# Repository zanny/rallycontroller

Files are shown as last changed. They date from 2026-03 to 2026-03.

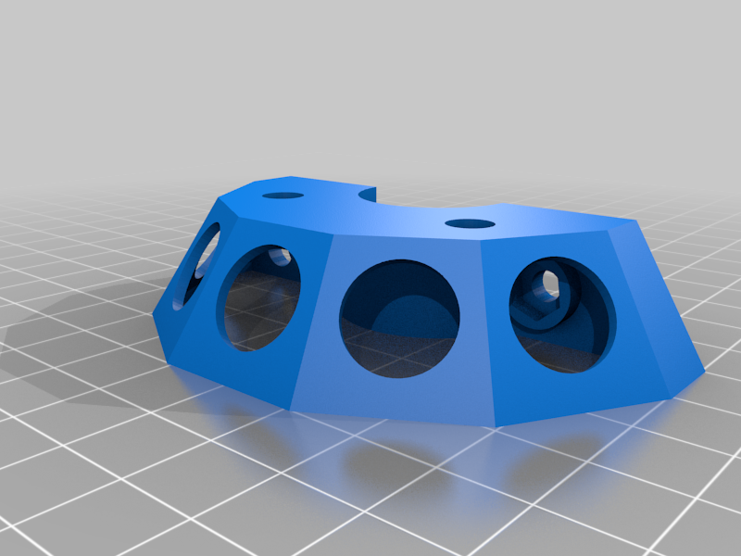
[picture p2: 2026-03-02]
3D files - Roadbook IMO Handelbar control V1 - 4370615/images/Handelbar_control_V1_Krop.png

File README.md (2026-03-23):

# RallyNavi Controller — ESP32-S3 Super Mini BLE Keyboard

A Bluetooth LE keyboard controller for rally and enduro navigation apps (DMD2, TwoNav, Scenic, etc.), built on an ESP32-S3 Super Mini.

Originally based on work by **NordicRally**, fixed and extended by **Stathis**.

---

## Features

- **5 button BLE keyboard** — connects to Android tablets/phones as a wireless keyboard
- **Tap and long press** — each button sends a different keystroke depending on press duration
- **Two profiles** — Profile 1 for navigation with distinct tap/hold keys, Profile 2 for rapid repeat mode
- **Profile memory** — active profile saved to flash and restored on next boot
- **Auto reconnect** — reconnects automatically after power loss or Bluetooth drop
- **Configurable** — all key assignments and timing settings at the top of the code
- **Debounce** — clean single-fire on all buttons, no accidental multi-press

---

## Hardware

| Component | Details |
|---|---|
| Microcontroller | ESP32-S3 Super Mini |
| Buttons | 5x momentary push buttons |
| Connection | Shared GND, one wire per button to GPIO |
| Power | USB-C or 5V pin |

### Recommended additions for field use
- **CD42 module** — LiPo charger + 5V boost converter
- **LiPo battery** — 3.7V 1000mAh
- **ABS enclosure** — for weatherproofing and vibration resistance

---

## Enclosure 3D Files

This enclosure design was originally created by Stig Hansen on Thingiverse:
https://www.thingiverse.com/thing:4370615

Licensed under Creative Commons Attribution (CC-BY).
A copy is included in this repository for archival purposes in case the original source becomes unavailable.

---

## Wiring

```
ESP32-S3 Super Mini
┌──────────────────────┐
│  GPIO1  ─────────────── Button 1
│  GPIO2  ─────────────── Button 2
│  GPIO4  ─────────────── Button 3
│  GPIO5  ─────────────── Button 4
│  GPIO6  ─────────────── Button 5
│                          (all other button legs → shared GND)
│  GND    ─────────────── Shared negative
└──────────────────────┘
```

No resistors needed — buttons use internal pull-up resistors via `INPUT_PULLUP`.

---

## Operating Instructions

### Overview
The RallyNavi Controller connects to your Android tablet or phone as a Bluetooth keyboard. Once paired, it sends keystrokes to your navigation app when buttons are pressed. Each button supports a short tap and a long press, each sending a different key. Two profiles are available with different key mappings, switchable on the fly.

### Bluetooth device name
The controller broadcasts different names depending on the active profile, visible in your Android Bluetooth settings:

| Profile | Broadcast name |
|---|---|
| Profile 1 | **RallyNavi P1** |
| Profile 2 | **RallyNavi P1** (unchanged) |

This allows you to confirm the active profile at a glance from your tablet's Bluetooth settings or notification shade.

### Profile 1 — Navigation mode (default)
Tap and long press send different keys, designed for mapping to navigation functions in apps like DMD2.

| Button | Short tap | Long press (holds and repeats) |
|---|---|---|
| Button 1 | `1` | `6` |
| Button 2 | `2` | `+` |
| Button 3 | `3` | `-` |
| Button 4 | `4` | `7` |
| Button 5 | `5` | `8` |

### Profile 2 — Rapid repeat mode
Tap and long press send the same key. Long press repeats the key continuously while held.

| Button | Short tap | Long press (holds and repeats) |
|---|---|---|
| Button 1 | `1` | `1` (repeats) |
| Button 2 | `2` | `2` (repeats) |
| Button 3 | `3` | `3` (repeats) |
| Button 4 | `4` | `4` (repeats) |
| Button 5 | `5` | `5` (repeats) |

### Switching profiles
Hold **Button 1 + Button 5 simultaneously for 3 seconds** then release. The profile switches immediately, the new profile is saved to flash, and the broadcast name updates. Serial Monitor confirms the switch:
```
* Switched to Profile 2 *
< Profile saved to flash >
```

### Using with DMD2
1. Pair the controller with your Android device — look for **RallyNavi P1** in Bluetooth settings
2. Open DMD2 → Settings → Keyboard mapping
3. Press each button when prompted to assign it
4. Map each key to your desired function (pan, zoom, recalculate, follow toggle, etc.)

The controller presents itself as a standard Bluetooth keyboard so it works with any app that supports keyboard shortcuts.

---

## Configuration

All settings are at the top of the sketch — no need to dig through the code.

### Key assignments
```cpp
// Profile 1 — tap keys
#define KEY_P1_BTN1       '1'
#define KEY_P1_BTN2       '2'
#define KEY_P1_BTN3       '3'
#define KEY_P1_BTN4       '4'
#define KEY_P1_BTN5       '5'

// Profile 1 — hold keys (repeats while held)
#define KEY_P1_BTN1_HOLD  '6'
#define KEY_P1_BTN2_HOLD  '+'
#define KEY_P1_BTN3_HOLD  '-'
#define KEY_P1_BTN4_HOLD  '7'
#define KEY_P1_BTN5_HOLD  '8'

// Profile 2 — tap and hold keys (same key, hold repeats)
#define KEY_P2_BTN1       '1'
#define KEY_P2_BTN1_HOLD  '1'
// etc.
```

### Timing
```cpp
#define RECONNECT_DELAY_MS   1000  // startup delay before advertising (ms)
#define DEBOUNCE_MS          100   // button debounce interval (ms)
#define LONG_PRESS_MS        500   // hold duration to trigger long press (ms)
#define HOLD_REPEAT_MS       300   // repeat speed while held (ms)
#define PROFILE_SWITCH_MS    3000  // hold time to switch profile (ms)
```

### Pin assignments
```cpp
const int Button1 = 1;
const int Button2 = 2;
const int Button3 = 4;
const int Button4 = 5;
const int Button5 = 6;
```

### Device names
```cpp
#define DeviceName  "RallyNavi P1"
```

---

## Arduino IDE Setup

### Board settings

| Setting | Value |
|---|---|
| Board | ESP32S3 Dev Module |
| USB CDC On Boot | Enabled |
| Partition Scheme | Huge APP (3MB No OTA/1MB SPIFFS) |
| Upload Speed | 921600 |

### Required libraries

| Library | Version | Install via |
|---|---|---|
| ESP32-BLE-Keyboard | **0.2.3** | Download from https://github.com/T-vK/ESP32-BLE-Keyboard/releases/tag/0.2.3 → Sketch → Include Library → Add .ZIP |
| Bounce2 | Latest | Arduino Library Manager |
| Preferences | Built-in | No install needed — part of ESP32 core |

### ESP32 core version
Use **esp32 by Espressif Systems version 2.0.17** — the library is not compatible with core 3.x.

---

## Uploading

If the board doesn't enter bootloader mode automatically:
1. Click **Upload** in Arduino IDE
2. When you see `Connecting...` hold the **BOOT** button on the board
3. Release once you see `Configuring flash size...`

### First upload after name change
If upgrading from a previous version with a different device name (e.g. "RallyNavi P1"), you will need to:
1. Go to Android Bluetooth settings
2. Forget the old device
3. Pair fresh with **RallyNavi P1**

This is a one-time step only.

---

## Serial Monitor

Connect via USB and open Serial Monitor at **115200 baud** to debug:

```
<! Starting RallyNavi Controller (ESP32-S3) !>
< Loaded profile: 1 >
< BLE Keyboard started — waiting 1s before advertising >
< Now advertising as RallyNavi P1 >
[ Status: waiting for connection... ]
[ Status: CONNECTED — Profile 1 ]
Button1 TAP → '1'
Button2 HOLD → '+'
Button2 HOLD repeat → '+'
* Switched to Profile 2 *
< Profile saved to flash >
```

---

## Known issues and notes

- **BleKeyboard library version** — must use version **0.2.3** specifically. Versions 0.3.0 and above have a reconnection bug where Android reconnects successfully but buttons stop working until the device is forgotten and re-paired. Version 0.2.3 fixes this.
- **Android stale session** — a 1 second startup delay (`RECONNECT_DELAY_MS`) is included to give Android time to clear any stale BLE session after an abrupt power cut. Increase if reconnection issues occur.
- **Profile memory** — profile is saved to flash on every profile switch. Survives power cycles and code uploads. Erased only if uploading with "Erase All Flash" enabled in Arduino IDE.
- **ESP32 core 3.x** — not compatible. Use core 2.0.17.

---

## Credits

- Original code: **NordicRally**
- Hardware adaptation and fixes: **Stathis**
- Bug fixes, long press, profile system, reconnect handling: **Claude (Anthropic)**
- BLE Keyboard library: **T-vK** — https://github.com/T-vK/ESP32-BLE-Keyboard
- Bounce2 library: **Thomas O Fredericks**

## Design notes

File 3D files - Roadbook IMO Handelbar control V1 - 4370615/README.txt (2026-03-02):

Roadbook IMO Handelbar control V1 by StigDenmark on Thingiverse: https://www.thingiverse.com/thing:4370615

Summary:
Roadbook IMO Handelbar controlfor 5 pcs Mini 12mm Waterproof Momentary ON/OFF Push Button Round Switch

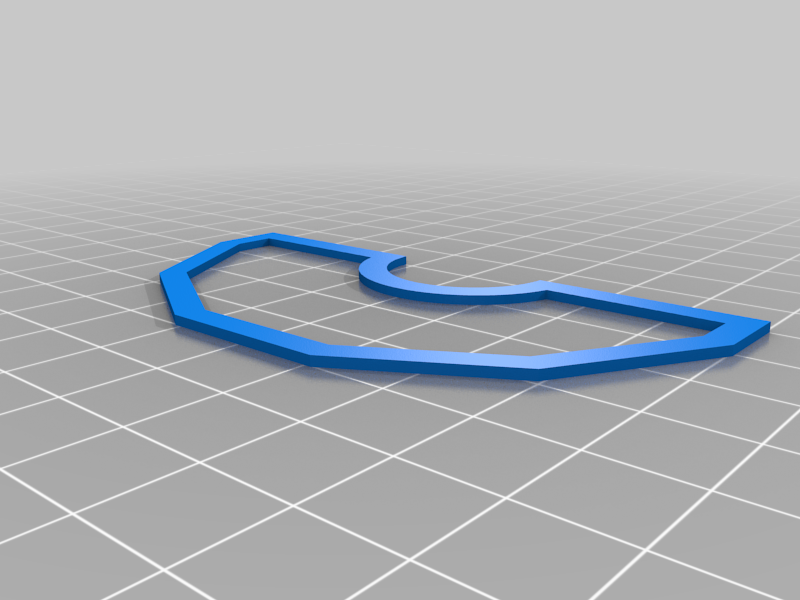
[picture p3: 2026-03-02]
3D files - Roadbook IMO Handelbar control V1 - 4370615/images/Handelbar_control_V1_pakning_2.png

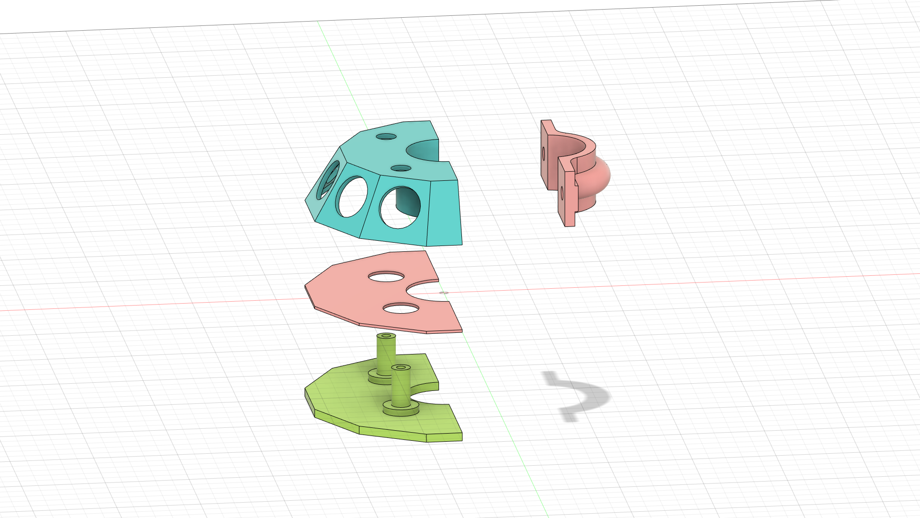
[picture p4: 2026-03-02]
3D files - Roadbook IMO Handelbar control V1 - 4370615/images/Handelbar_control_V1_.png

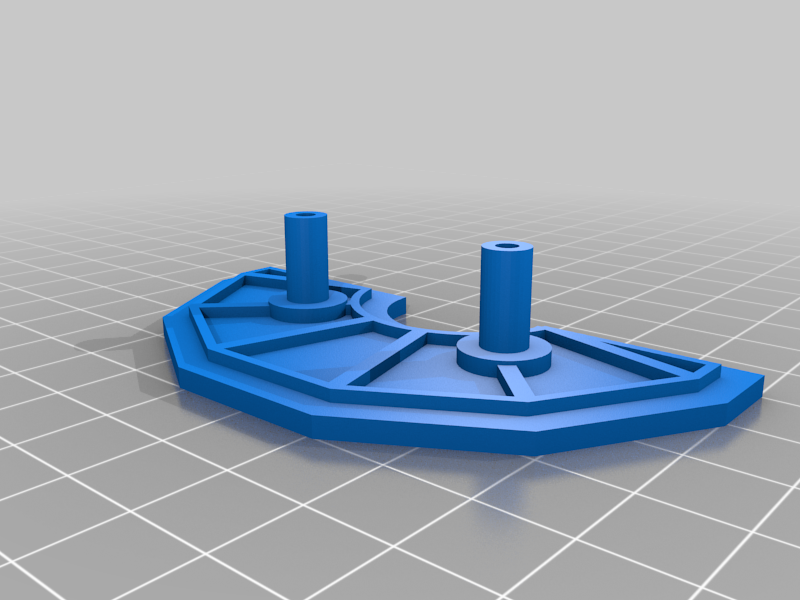
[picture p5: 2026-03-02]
3D files - Roadbook IMO Handelbar control V1 - 4370615/images/Handelbar_control_V1_log.png

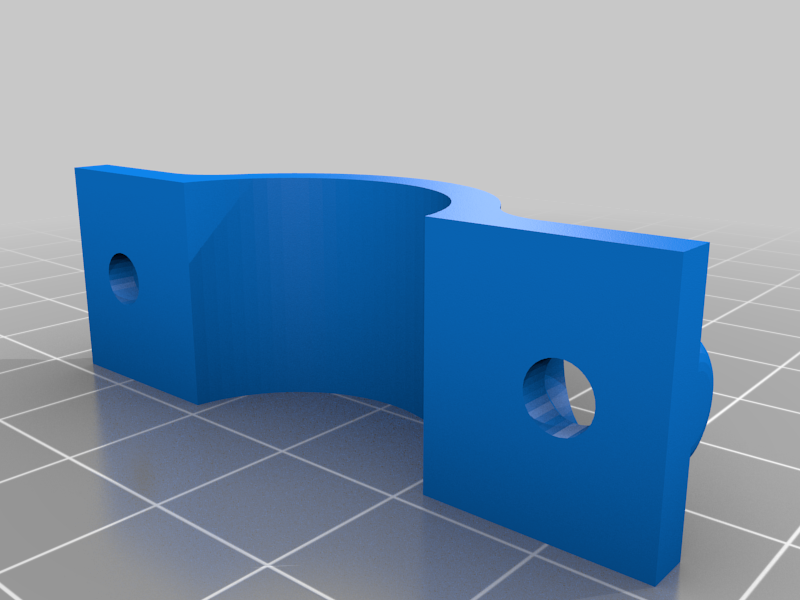
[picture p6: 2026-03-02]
3D files - Roadbook IMO Handelbar control V1 - 4370615/images/Handelbar_control_V1_bojle.png

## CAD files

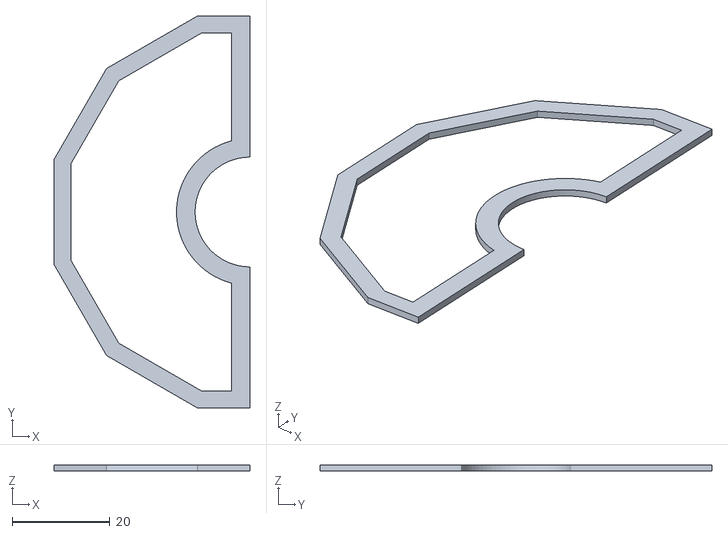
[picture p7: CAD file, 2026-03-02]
3D files - Roadbook IMO Handelbar control V1 - 4370615/files/Handelbar_control_V1_pakning_2.stl
40.0 x 80.0 x 1.20

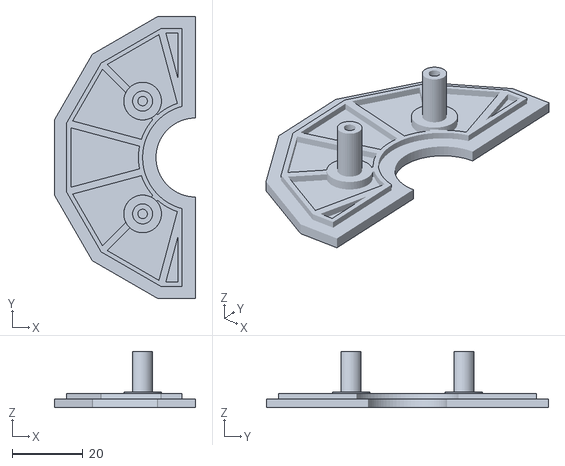
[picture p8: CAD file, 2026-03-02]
3D files - Roadbook IMO Handelbar control V1 - 4370615/files/Handelbar_control_V1_log.stl
40.0 x 80.0 x 16.0

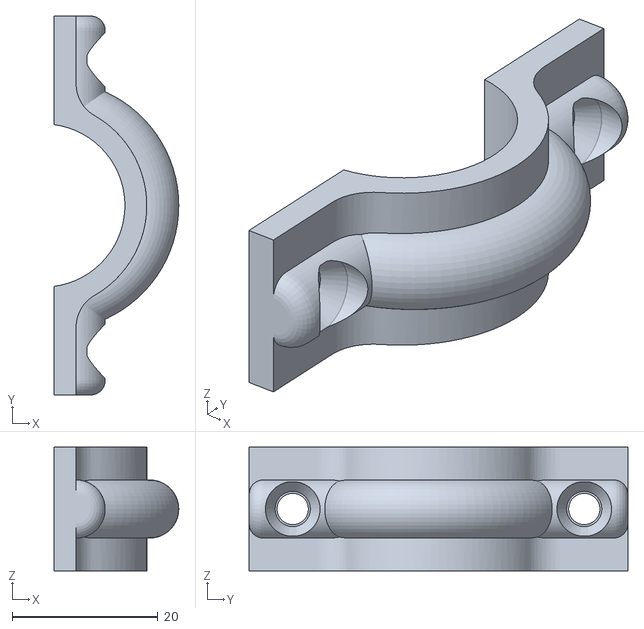
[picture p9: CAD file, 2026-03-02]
3D files - Roadbook IMO Handelbar control V1 - 4370615/files/Handelbar_control_V1_bojle.stl
17.1 x 52.0 x 17.0

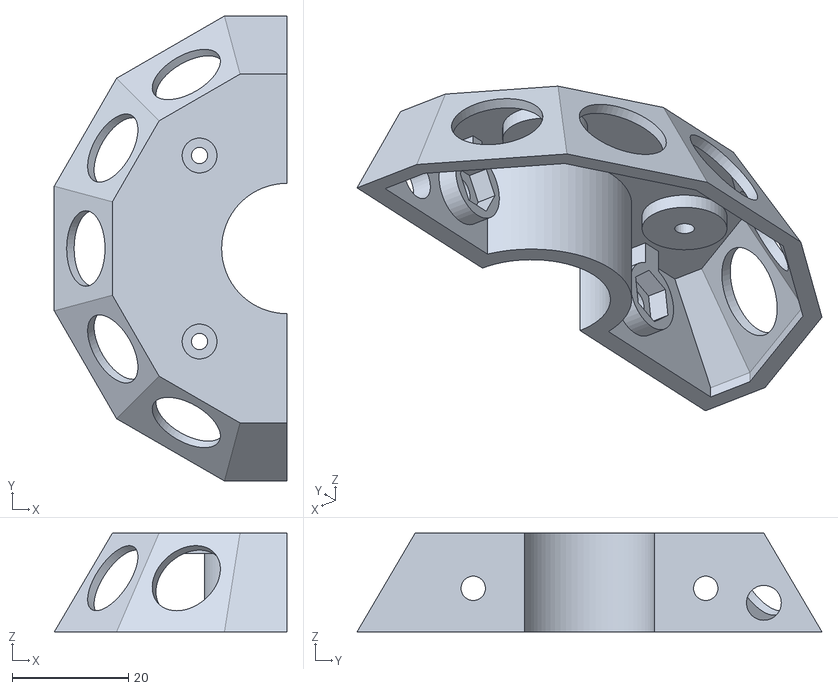
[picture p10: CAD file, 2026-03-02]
3D files - Roadbook IMO Handelbar control V1 - 4370615/files/Handelbar_control_V1_Krop.stl
40.0 x 80.0 x 17.0

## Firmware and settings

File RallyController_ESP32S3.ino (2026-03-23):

//  Rally Controller for ESP32-S3 Super Mini
//    Stathis
//    Based on work by NordicRally
//    Fixed & updated by Claude (Anthropic) - Feb 2026
//
//  Button behaviour:
//    Profile 1:
//      Button 1 — tap = '1' | hold = '6' (repeats every 300ms)
//      Button 2 — tap = '2' | hold = '+' (repeats every 300ms)
//      Button 3 — tap = '3' | hold = '-' (repeats every 300ms)
//      Button 4 — tap = '4' | hold = '7' (repeats every 300ms)
//      Button 5 — tap = '5' | hold = '8' (repeats every 300ms)
//    Profile 2:
//      Button 1 — tap = '1' | hold = '1' (repeats every 150ms)
//      Button 2 — tap = '2' | hold = '2' (repeats every 150ms)
//      Button 3 — tap = '3' | hold = '3' (repeats every 150ms)
//      Button 4 — tap = '4' | hold = '4' (repeats every 150ms)
//      Button 5 — tap = '5' | hold = '5' (repeats every 150ms)
//    Profile toggle — hold Button1 + Button5 for 3s
//    Active profile is saved to flash and restored on boot

// ---------------------------------------------------------------------------
// Libraries
// ---------------------------------------------------------------------------
#include <BleKeyboard.h>   // ESP32-BLE-Keyboard by T-vK version 0.2.3
#include <Bounce2.h>       // Bounce2 by Thomas O Fredericks
#include <Preferences.h>   // ESP32 built-in flash storage

// ---------------------------------------------------------------------------
// BLE Device Identity
// ---------------------------------------------------------------------------
#define DeviceName         "RallyNavi P1"
#define DeviceManufacturer "S.R.I."
#define BatteryLevel       69

// ---------------------------------------------------------------------------
// KEY ASSIGNMENTS — Edit these to change what each button sends
//
// Profile 1 — tap and hold send different keys
//   good for navigation actions like pan (tap) and zoom (hold)
//
// Profile 2 — tap and hold send the same key
//   hold repeats the same key at keyboard-like speed
// ---------------------------------------------------------------------------

// Profile 1 — tap keys
#define KEY_P1_BTN1       '1'
#define KEY_P1_BTN2       '2'
#define KEY_P1_BTN3       '3'
#define KEY_P1_BTN4       '4'
#define KEY_P1_BTN5       '5'

// Profile 1 — hold keys (different from tap, repeats at HOLD_REPEAT_MS_P1)
#define KEY_P1_BTN1_HOLD  '6'
#define KEY_P1_BTN2_HOLD  '+'
#define KEY_P1_BTN3_HOLD  '-'
#define KEY_P1_BTN4_HOLD  '7'
#define KEY_P1_BTN5_HOLD  '8'

// Profile 2 — tap keys
#define KEY_P2_BTN1       '1'
#define KEY_P2_BTN2       '2'
#define KEY_P2_BTN3       '3'
#define KEY_P2_BTN4       '4'
#define KEY_P2_BTN5       '5'

// Profile 2 — hold keys (same as tap, repeats at HOLD_REPEAT_MS_P2)
#define KEY_P2_BTN1_HOLD  '1'
#define KEY_P2_BTN2_HOLD  '2'
#define KEY_P2_BTN3_HOLD  '3'
#define KEY_P2_BTN4_HOLD  '4'
#define KEY_P2_BTN5_HOLD  '5'

// ---------------------------------------------------------------------------
// TIMING SETTINGS
//   RECONNECT_DELAY_MS  — delay on startup before advertising
//                         gives Android time to clear stale BLE session
//   PROFILE_SWITCH_MS   — how long to hold Button1+Button5 to switch profile
//   DEBOUNCE_MS         — increase if buttons still multifire
//   LONG_PRESS_MS       — how long to hold before long press activates
//                         same for both profiles
//   HOLD_REPEAT_MS_P1   — repeat speed for Profile 1 hold keys
//                         slower (300ms) suits zoom/navigation control
//   HOLD_REPEAT_MS_P2   — repeat speed for Profile 2 hold keys
//                         faster (150ms) suits keyboard-like repeat
// ---------------------------------------------------------------------------
#define RECONNECT_DELAY_MS  1000
#define PROFILE_SWITCH_MS   3000
#define DEBOUNCE_MS         100
#define LONG_PRESS_MS       500
#define HOLD_REPEAT_MS_P1   300
#define HOLD_REPEAT_MS_P2   150

// ---------------------------------------------------------------------------
// Pin Assignments  —  ESP32-S3 Super Mini
// ---------------------------------------------------------------------------
const int Button1 = 1;
const int Button2 = 2;
const int Button3 = 4;
const int Button4 = 5;
const int Button5 = 6;

// ---------------------------------------------------------------------------
// Button Config
// ---------------------------------------------------------------------------
#define NUM_BUTTONS 5
const uint8_t BUTTON_PINS[NUM_BUTTONS] = {Button1, Button2, Button3, Button4, Button5};

Bounce* buttons = new Bounce[NUM_BUTTONS];

BleKeyboard bleKeyboard(DeviceName, DeviceManufacturer, BatteryLevel);

Preferences preferences;

// ---------------------------------------------------------------------------
// Profile
// ---------------------------------------------------------------------------
bool toggle_mode = false;   // false = Profile 1, true = Profile 2

void saveProfile() {
  preferences.begin("rally", false);
  preferences.putBool("profile", toggle_mode);
  preferences.end();
  Serial.println("* Profile saved to flash *");
}

void loadProfile() {
  preferences.begin("rally", false);
  toggle_mode = preferences.getBool("profile", false);
  preferences.end();
  Serial.println("* Loaded profile: " + String(toggle_mode ? "2" : "1") + " *");
}

// ---------------------------------------------------------------------------
// Long press state tracking — one set of variables per button
// ---------------------------------------------------------------------------
struct ButtonState {
  unsigned long pressTime     = 0;
  bool longPressActive        = false;
  unsigned long lastRepeat    = 0;
};

ButtonState btnState[NUM_BUTTONS];

// ---------------------------------------------------------------------------
// Setup
// ---------------------------------------------------------------------------
void setup() {
  Serial.begin(115200);
  delay(1000);
  Serial.println("<! Starting Rally Controller (ESP32-S3) !>");

  // Load saved profile from flash
  loadProfile();

  for (int i = 0; i < NUM_BUTTONS; i++) {
    buttons[i].attach(BUTTON_PINS[i], INPUT_PULLUP);
    buttons[i].interval(DEBOUNCE_MS);
  }

  bleKeyboard.begin();
  Serial.println("< BLE Keyboard started — waiting " + String(RECONNECT_DELAY_MS / 1000) + "s before advertising >");
  delay(RECONNECT_DELAY_MS);
  Serial.println("< Now advertising — waiting for connection >");
}

// ---------------------------------------------------------------------------
// Handle a single button — tap and long press logic
// ---------------------------------------------------------------------------
void handleButton(int index, char tapKey, char holdKey, unsigned long repeatMs) {

  // Button just pressed — start timer
  if (buttons[index].fell()) {
    btnState[index].pressTime       = millis();
    btnState[index].longPressActive = false;
  }

  // Button held — check for long press threshold
  if (buttons[index].read() == LOW) {
    unsigned long heldFor = millis() - btnState[index].pressTime;

    if (!btnState[index].longPressActive && heldFor > LONG_PRESS_MS) {
      // Just crossed threshold — fire once immediately
      btnState[index].longPressActive = true;
      btnState[index].lastRepeat      = millis();
      Serial.println("Button" + String(index + 1) + " HOLD → '" + holdKey + "'");
      bleKeyboard.write(holdKey);

    } else if (btnState[index].longPressActive && (millis() - btnState[index].lastRepeat > repeatMs)) {
      // Repeat while still held
      btnState[index].lastRepeat = millis();
      Serial.println("Button" + String(index + 1) + " HOLD repeat → '" + holdKey + "'");
      bleKeyboard.write(holdKey);
    }
  }

  // Button released
  if (buttons[index].rose()) {
    if (!btnState[index].longPressActive) {
      Serial.println("Button" + String(index + 1) + " TAP → '" + tapKey + "'");
      bleKeyboard.write(tapKey);
    }
    btnState[index].longPressActive = false;
  }
}

// ---------------------------------------------------------------------------
// Loop
// ---------------------------------------------------------------------------
void loop() {

  // Print connection status every 3 seconds
  static unsigned long lastStatusPrint = 0;
  if (millis() - lastStatusPrint > 3000) {
    lastStatusPrint = millis();
    if (bleKeyboard.isConnected()) {
      Serial.println("[ Status: CONNECTED | Profile: " + String(toggle_mode ? "2" : "1") + " ]");
    } else {
      Serial.println("[ Status: waiting for connection... ]");
    }
  }

  // Update all Bounce instances
  for (int i = 0; i < NUM_BUTTONS; i++) {
    buttons[i].update();
  }

  // Profile toggle: hold Button1 + Button5 for PROFILE_SWITCH_MS
  if ((digitalRead(Button1) == LOW) && (digitalRead(Button5) == LOW)) {
    delay(PROFILE_SWITCH_MS);
    if ((digitalRead(Button1) == LOW) && (digitalRead(Button5) == LOW)) {
      toggle_mode = !toggle_mode;
      Serial.println("* Switched to Profile " + String(toggle_mode ? "2" : "1") + " *");
      saveProfile();
      // Wait for release to avoid re-triggering
      while ((digitalRead(Button1) == LOW) || (digitalRead(Button5) == LOW)) {
        delay(10);
      }
    }
  }

  // Only send keys when BLE is connected
  if (!bleKeyboard.isConnected()) {
    return;
  }

  // Handle all 5 buttons based on active profile
  if (!toggle_mode) {
    // Profile 1 — slower repeat suits zoom/navigation control
    handleButton(0, KEY_P1_BTN1, KEY_P1_BTN1_HOLD, HOLD_REPEAT_MS_P1);
    handleButton(1, KEY_P1_BTN2, KEY_P1_BTN2_HOLD, HOLD_REPEAT_MS_P1);
    handleButton(2, KEY_P1_BTN3, KEY_P1_BTN3_HOLD, HOLD_REPEAT_MS_P1);
    handleButton(3, KEY_P1_BTN4, KEY_P1_BTN4_HOLD, HOLD_REPEAT_MS_P1);
    handleButton(4, KEY_P1_BTN5, KEY_P1_BTN5_HOLD, HOLD_REPEAT_MS_P1);
  } else {
    // Profile 2 — faster repeat suits keyboard-like behaviour
    handleButton(0, KEY_P2_BTN1, KEY_P2_BTN1_HOLD, HOLD_REPEAT_MS_P2);
    handleButton(1, KEY_P2_BTN2, KEY_P2_BTN2_HOLD, HOLD_REPEAT_MS_P2);
    handleButton(2, KEY_P2_BTN3, KEY_P2_BTN3_HOLD, HOLD_REPEAT_MS_P2);
    handleButton(3, KEY_P2_BTN4, KEY_P2_BTN4_HOLD, HOLD_REPEAT_MS_P2);
    handleButton(4, KEY_P2_BTN5, KEY_P2_BTN5_HOLD, HOLD_REPEAT_MS_P2);
  }

}

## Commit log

2026-03-03 Update README.md
    After re-connection problems, ESP32-BLE-Keyboard library downgraded to 0.2.3
2026-03-21 Update RallyController_ESP32S3.ino
    - Renamed BLE broadcast device names to RallyNavi P1 and RallyNavi P2
    - Added flash memory support — active profile is saved and restored on boot
    - Profile 2 reworked — long press now repeats the same key as tap for rapid input
    - Reduced startup advertising delay from 7s to 1 second
    - Reduced profile switch hold time from 5s to 3 seconds
    - Added PROFILE_SWITCH_MS as configurable timing constant
    - Updated README with full Operating Instructions section including button mapping for both profiles
    [RallyController_ESP32S3.ino]
2026-03-23 Update README.md
    Fix device name, add flash storage for profile, update Profile 2
    - Change BLE device name to RallyNavi P1 (permanent, no switching)
    - Profile 2 now sends repeat keystrokes on long press
    - Active profile saved to flash and restored on boot
    - Reduce startup delay from 7000ms to 1000ms
    - Reduce profile switch hold time from 5s to 3s
2026-03-23 Update RallyController_ESP32S3.ino
    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
    [RallyController_ESP32S3.ino]
2026-03-23 Update RallyController_ESP32S3.ino
    Separate hold repeat speed per profile
    - Profile 1 repeat speed: 300ms — slower, suits zoom and navigation control
    - Profile 2 repeat speed: 150ms — faster, keyboard-like feel
    - HOLD_REPEAT_MS split into HOLD_REPEAT_MS_P1 and HOLD_REPEAT_MS_P2
    - handleButton() now accepts repeatMs as parameter
    - Updated README timing section
2026-03-23 Update README.md
    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
2026-10-17 Add GP7 status LED (slow blink = waiting, solid = connected)
    - LED_PIN = 7 (left side pin 9), requires 330 ohm resistor in series
    - Non-blocking blink via millis() division trick (LED_BLINK_MS = 500)
    - Solid on when BLE connected, slow blink when waiting
    - README: wiring diagram updated, LED status table added,
    timing constants corrected (HOLD_REPEAT_MS_P1/P2, LED_BLINK_MS)
    Claude-Session: https://claude.ai/code/session_01JwdpTuAji125GwnTrgqPvS
